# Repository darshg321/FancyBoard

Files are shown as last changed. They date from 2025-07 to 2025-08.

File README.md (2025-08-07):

# FancyBoard

FancyBoard is a custom hot-swappable mechanical keyboard inspired by the k.no.b.1 from Work Louder.

- Hot Swappable
- BlueMicro Firmware
- Low Profile
- Bluetooth & USB-C
- 1.9" IPS Display
- 65% layout
- 2 Dials

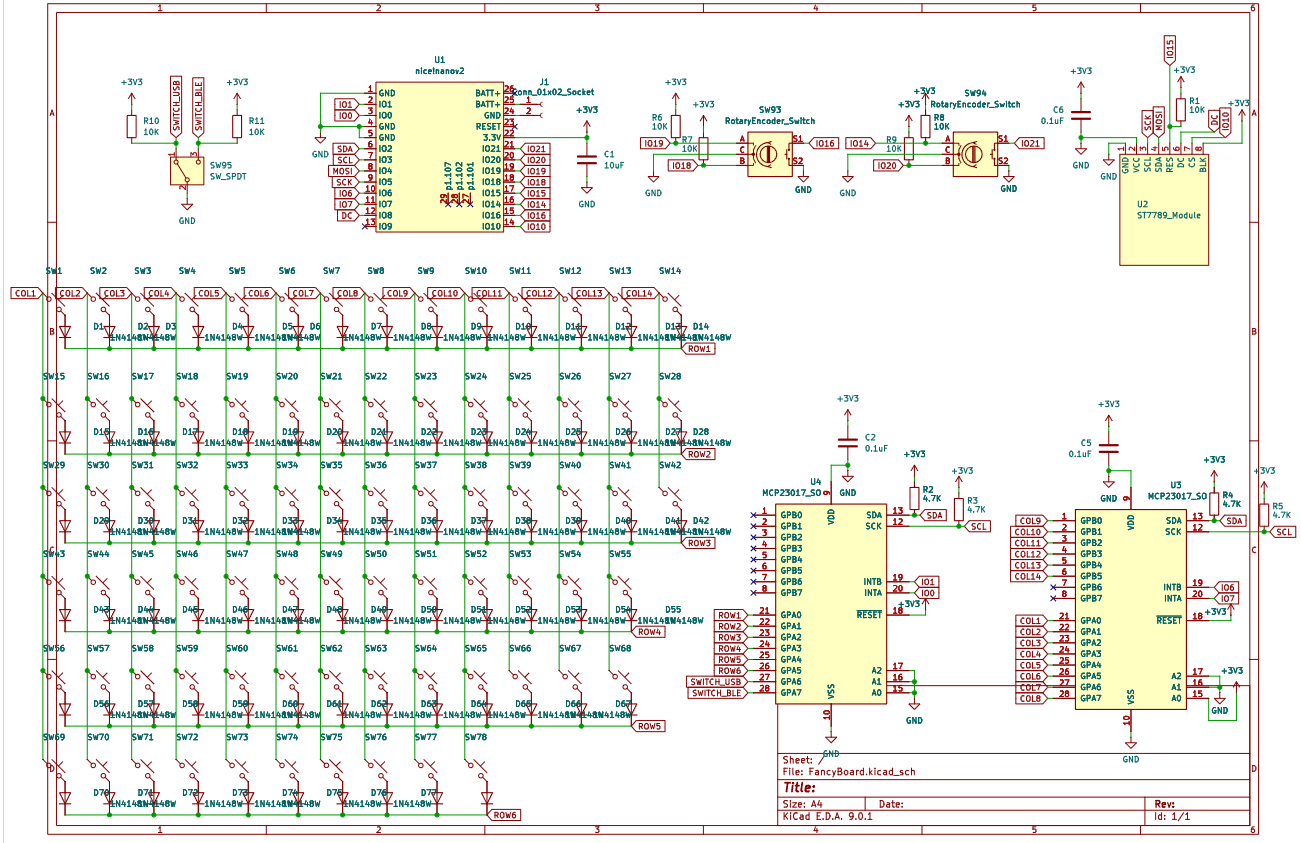
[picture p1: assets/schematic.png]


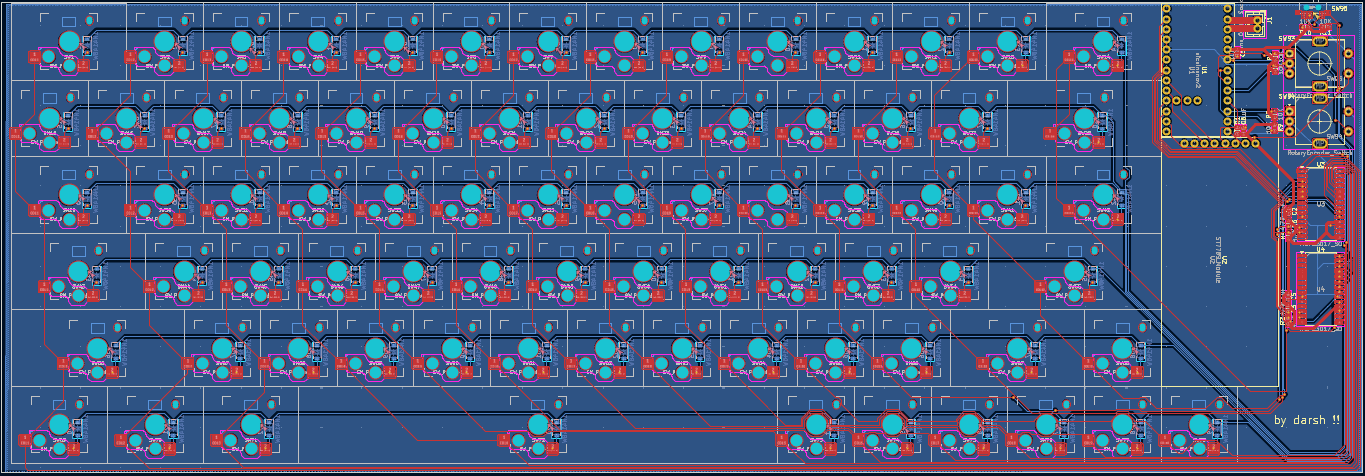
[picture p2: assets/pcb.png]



i made this keyboard because i saw the KNOB keyboard on reels, and thought it was probably the nicest looking keyboard ive seen, but unfortunately its like 400usd, way too expensive

i wanted to learn how to make a full keyboard after hackpad anyways, so i designed this. i also want a bluetooth keyboard because my current keyboard has a cable thats very annoying, and i wanted to replace it.

## BOM
|Reference |Value |Footprint |Qty|Link |Price (USD)|
|---|---|---|---|---|---|
|C1 |10uF |Capacitor_SMD:C_0603_1608Metric |1  |https://www.aliexpress.com/item/1005002761630440.html|3.13 |
|C2,C5,C6 |0.1uF |Capacitor_SMD:C_0603_1608Metric |3  | | |
|D1-D79 |1N4148W |Diode_SMD:D_SOD-123 |78 |https://www.aliexpress.com/item/1005006123061230.html|2.8 |
|J1 |Conn_01x02_Socket |Connector_JST:JST_PH_B2B-PH-K_1x02_P2.00mm_Vertical |1  |https://www.aliexpress.com/item/1005004955655144.html|2 |
|R1,R6,R7,R8,R9,R10,R11|10K |Resistor_SMD:R_0603_1608Metric |7  |https://www.aliexpress.com/item/1005008912576822.html|1.9 |
|R2,R3,R4,R5 |4.7K |Resistor_SMD:R_0603_1608Metric |4  |https://www.aliexpress.com/item/1005008912576822.html|1.9 |
|SW2-SW78 |SW_Push_45deg |Kailh_PG1353_Hotswap:Kailh-PG1353-Hotswap |78 |https://www.aliexpress.com/item/1005008644185126.html|32.61 |
|SW93,SW94 |RotaryEncoder_Switch |Rotary_Encoder:RotaryEncoder_Alps_EC11E-Switch_Vertical_H20mm|2  |https://www.aliexpress.com/item/1005007644083514.html|2.25 |
|SW95 |SW_SPDT |MSK-12C02:MSK-12C02 |1  |https://www.aliexpress.com/item/1005009568929894.html|2.13 |
|U1 |nice!nanov2 |nice!nanov2:nice!nanov2 |1  |https://www.aliexpress.com/item/1005007266112508.html|3.02 |
|U2 |ST7789_Module |ST7789_Module:ST7789_Module |1  |https://www.aliexpress.com/item/1005006042323705.html|2.54 |
|U3,U4 |MCP23017_SO |Package_SO:SOIC-28W_7.5x17.9mm_P1.27mm |2  |https://www.aliexpress.com/item/1005009559642041.html|4.07 |
| |Kailh Choc Stabilizers | |1  |https://www.aliexpress.com/item/1005006528731543.html|8.65 |
| |Kailh Choc Keycaps | |78 |https://www.aliexpress.com/item/1005008146995393.html|15.76 |
| |Kalih Choc Hot Swap Sockets| |78 |https://www.aliexpress.com/item/1005006625852715.html|9.73 |
| |1s LiPo 500mAh Battery | |1  |https://www.aliexpress.com/item/1005007016796736.html|9.15 |
| |PCB | | |https://jlcpcb.com |19 |
| |M2 18mm Screw | | |https://www.aliexpress.com/item/1005007264845313.html|1.89 |
|Subtotal | | | | |122.53 |
|AliExpress Shipping | | | | |14.45 |
|JLCPCB Shipping | | | | |13.14 |
|Total | | | | |150.12 |

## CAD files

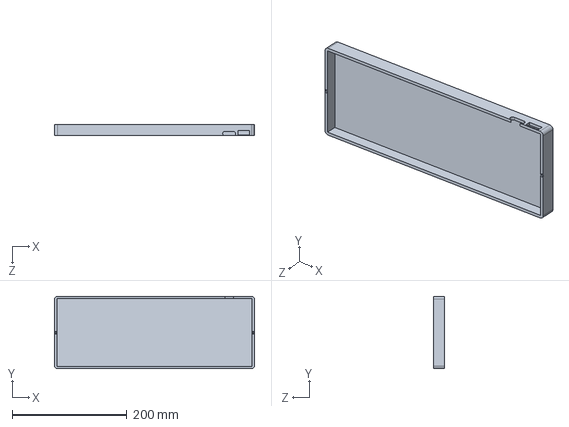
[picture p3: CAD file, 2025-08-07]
cad/bottom.SLDPRT
348.0 x 126.0 x 20.0 mm

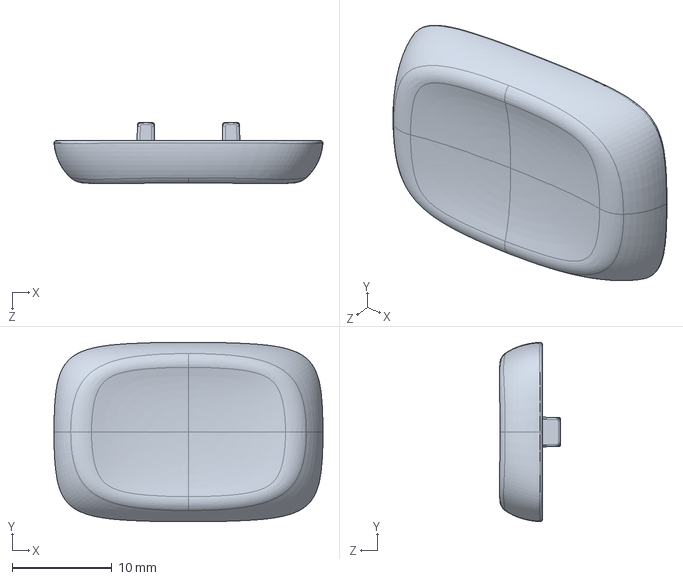
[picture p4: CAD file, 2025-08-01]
cad/keycaps/1.5u.SLDPRT
27.0 x 18.0 x 6.14 mm

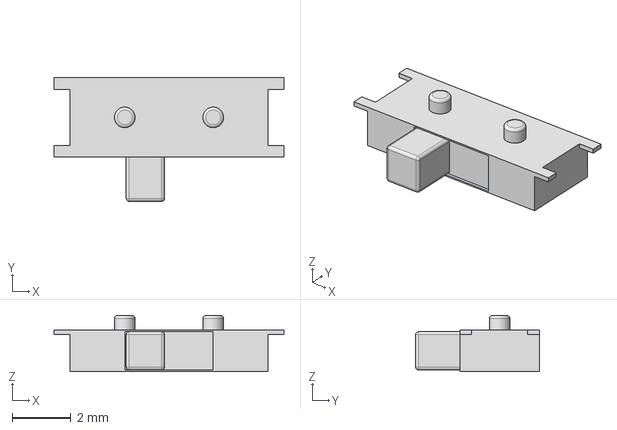
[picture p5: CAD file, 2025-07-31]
pcb/msk12c02.step
7.80 x 4.20 x 1.90 mm

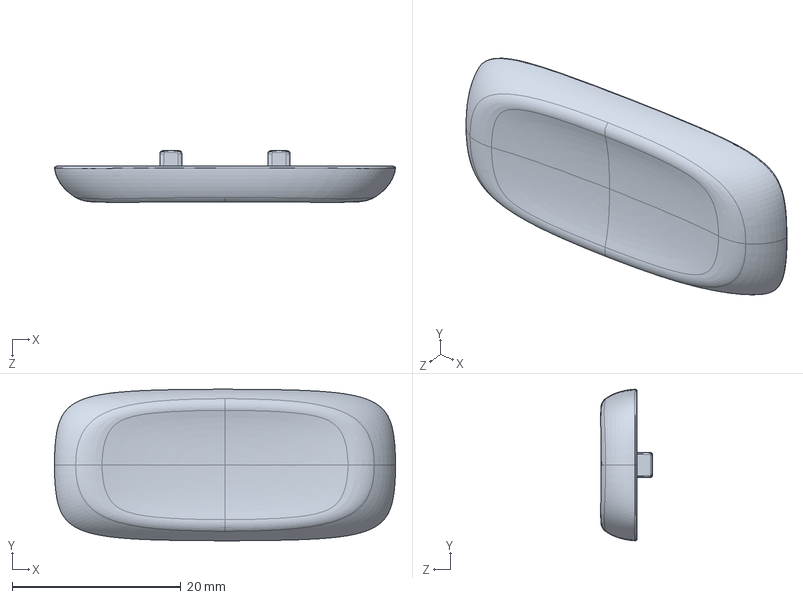
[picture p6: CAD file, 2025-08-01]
cad/keycaps/2.25u.SLDPRT
40.5 x 18.0 x 6.14 mm

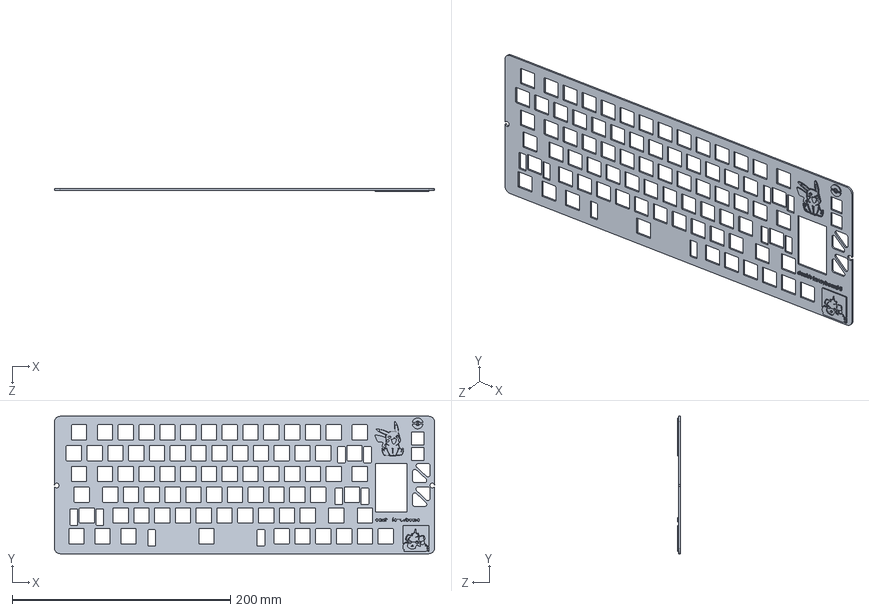
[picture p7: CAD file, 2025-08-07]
cad/top.SLDPRT
348.2 x 126.0 x 2.50 mm

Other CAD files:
cad/PCB Assembly/Kailh-Choc-Socket-CPG135001S30.SLDASM
cad/PCB Assembly/2.0 TFT IPS - Module.SLDASM
cad/PCB Assembly/2.0 TFT IPS - 22P - Reverse Mount - With Glass.SLDASM
cad/PCB Assembly/TSSOP-16 0.65p 4.4mm.SLDASM
cad/PCB Assembly/2.0 TFT IPS - Module_independant1.SLDASM
cad/PCB Assembly/USB C Female SMD v1.SLDASM
cad/PCB Assembly/nice!nano v2.SLDASM
cad/PCB Assembly/mcu-chip-ic-2set-leg v1.SLDASM
cad/PCB Assembly/2.0 TFT IPS - Module_independant.SLDASM
cad/PCB Assembly/FancyBoard 1.SLDASM
cad/PCB Assembly/TSSOP-16 0.65p 4.4mm v1.SLDASM
cad/PCB Assembly/Kailh LP Choc Burnt Orange.SLDPRT
production/bottom.STEP
cad/PCB Assembly/0603 Capacitor.SLDPRT
cad/PCB Assembly/0603 Resistor.SLDPRT
cad/PCB Assembly/2.0 TFT IPS - 22P - Reverse Mount - With Glass-0.SLDPRT
cad/PCB Assembly/2.0 TFT IPS - Glass - Rev.SLDPRT
cad/PCB Assembly/2.0 TFT IPS - Module - Board.SLDPRT
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

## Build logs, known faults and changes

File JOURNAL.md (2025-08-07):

---
title: "FancyBoard"
author: "Darsh Gupta"
description: "A custom, low-profile, hot-swappable mechanical keyboard."
created_at: "2025-07-28"
---

## time spent: 36 hours
## july 28th

speedrunning a keyboard before the 31st, just because

i was inspired for making this keyboard by the KNOB keyboard, which ive seen and always thought looked like the perfect keyboard. unfortunately, its $439, bad, so i'll try to make something similar for $150

KNOB:
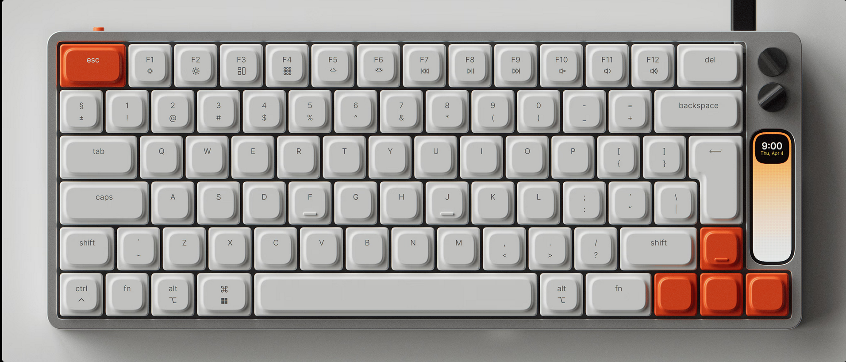
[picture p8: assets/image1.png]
KNOB


planned features:
- nice mechanical switches
- keycaps, i wont be using low profile because i personally dont like it
- hotswappable
- 2 dials
- oled screen
- both usb c and bluetooth connectivity
- usb c charging
- 3000mAh battery for big battery life

ill be using the nice!nano v2 because it consumes very little power, has battery charging built in, and has bluetooth HID + usb c HID already

parts list:

| Component | Part | Notes |
| --- | --- | --- |
| Microcontroller | Nice!Nano V2 | nRF52840 + integrated battery charger |
| Battery | 3.7V Li-ion 3000mAh (flat, JST-PH) | Rechargeable |
| USB Port | JST to USB-C charging cable | Board already has onboard USB |
| Rotary Encoder | EC11 w/ push button | For volume/menu |
| Screen | ST7789 1.14" | SPI, vertical https://www.aliexpress.com/item/1005009445748262.html |

| Component | Part | Notes |
| --- | --- | --- |
| Switches | 78x Tactile MX Switches | |
| Diodes | 1N4148W SMD | |
| Hotswap Sockets | 78x Kailh MX sockets | |
| Keycaps | SA / DSA / OEM profile | PC or PBT preferred |
| Encoder Knob | Aluminum / ABS cap | |

# schematic

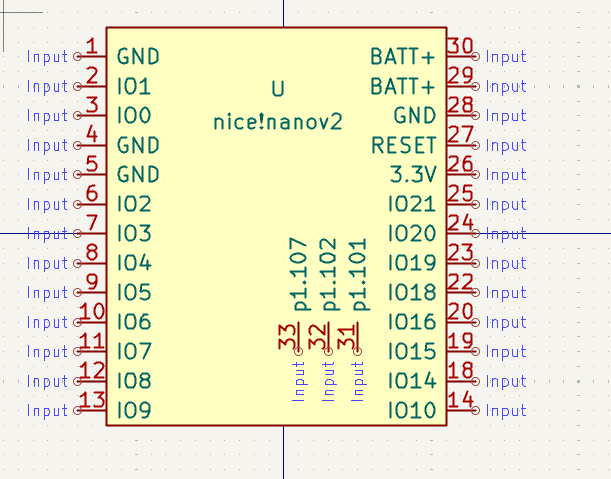
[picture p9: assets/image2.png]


microcontroller symbol done!

+3 hours

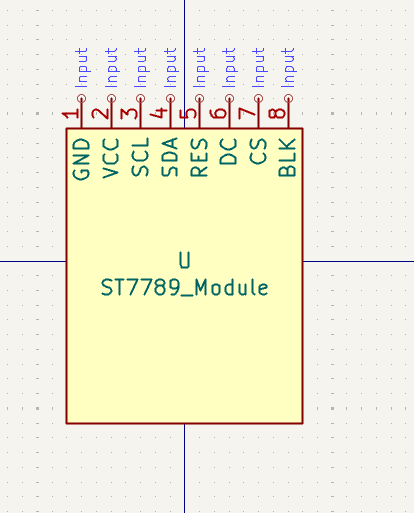
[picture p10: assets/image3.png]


done with ST7789_Module symbol

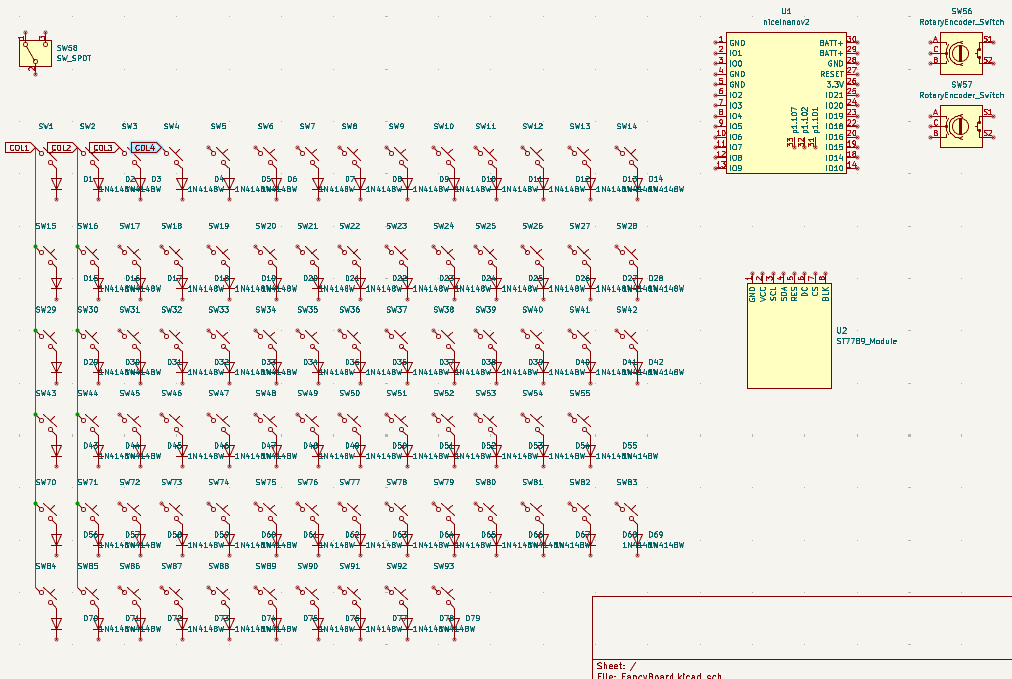
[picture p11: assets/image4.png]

current progress of schematic

+2 hours

adding 2 MCP23017 because i need a lot more io

## july 29th

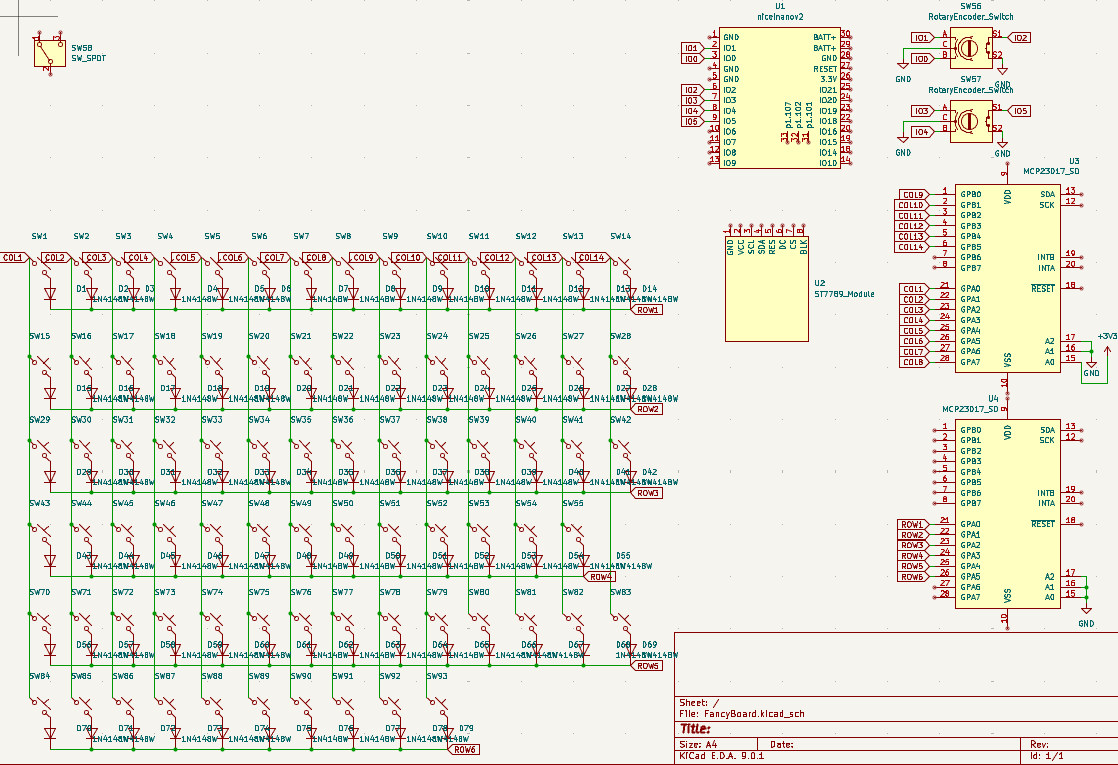
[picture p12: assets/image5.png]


added all the components, need to complete wiring

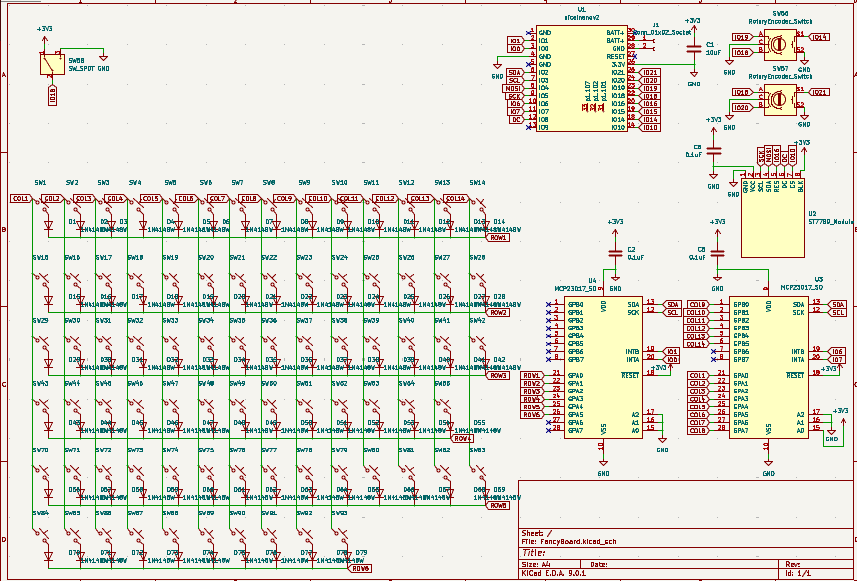
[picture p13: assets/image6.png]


finished most of everything, need to add some pull up resistors and capacitors and stuff

+3 hours

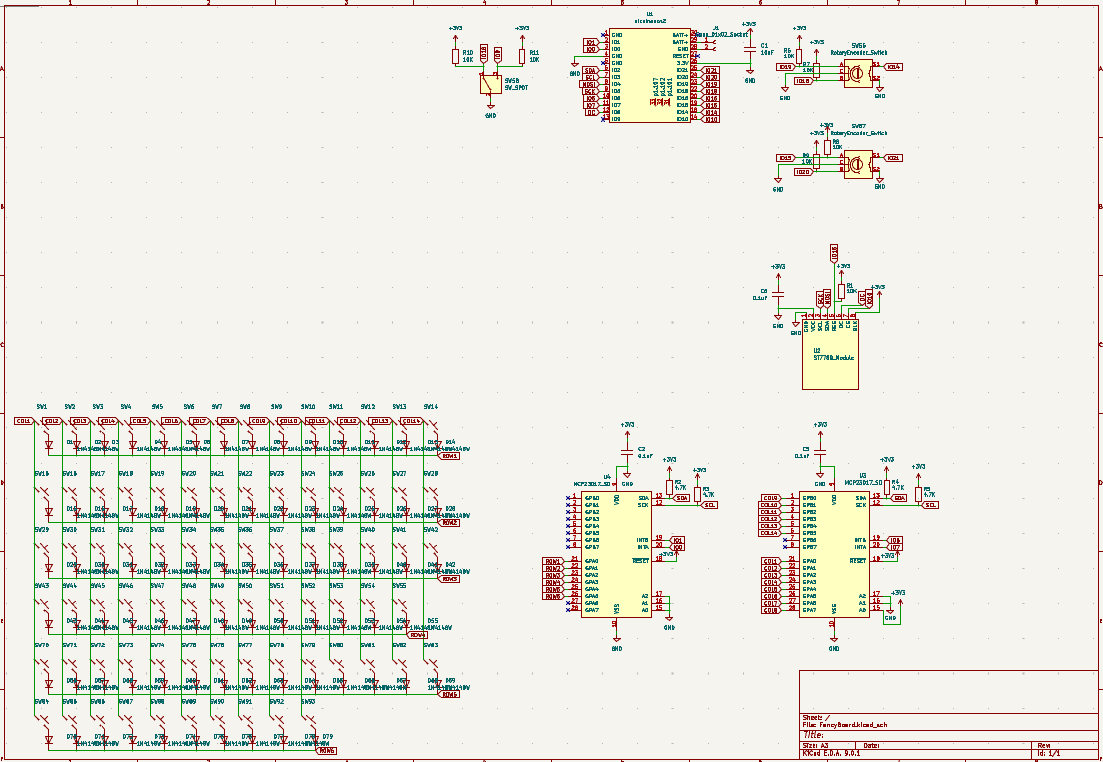
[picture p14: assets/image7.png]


done with schematic, pull ups and capacitors

need to make footprints and assignments

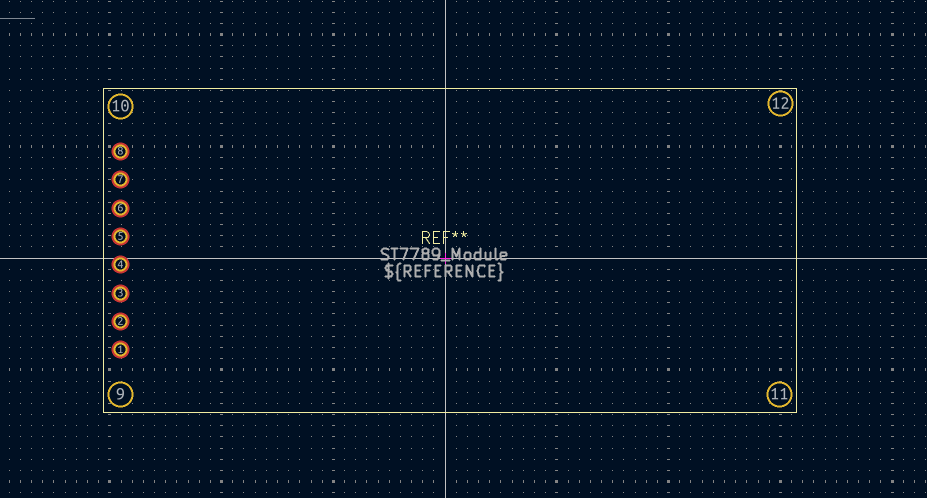
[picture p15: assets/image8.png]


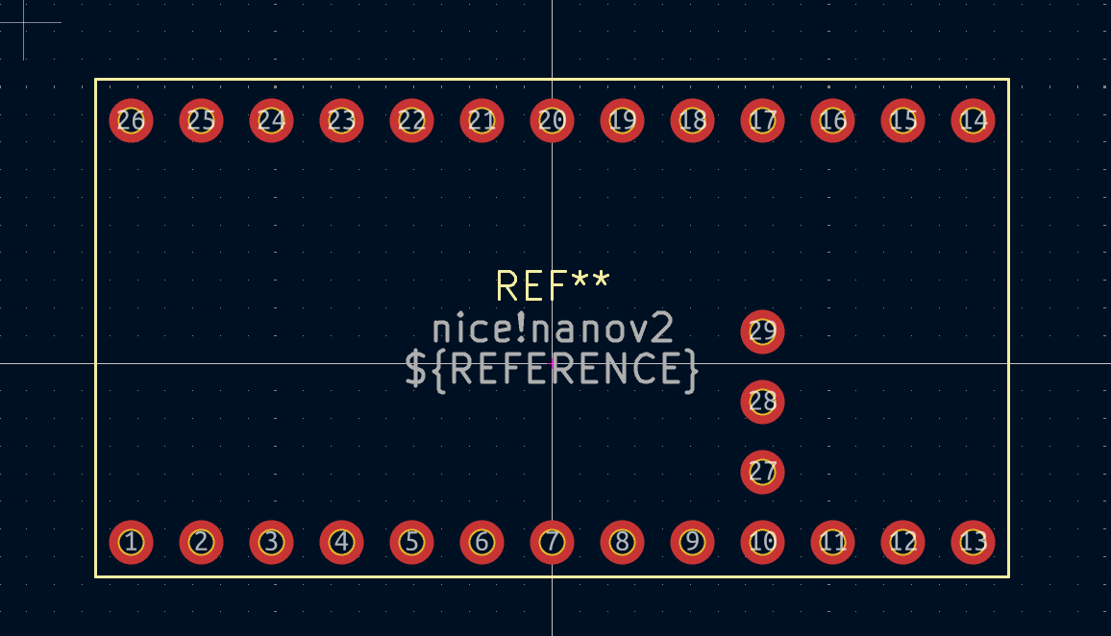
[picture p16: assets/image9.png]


done with both footprints

+3 hours

keycaps: https://www.aliexpress.com/item/1005004840360158.html

deciding on Kailih Choc V2 Low Profile Switches

stabalizers: https://www.aliexpress.com/item/1005001781468636.html

spdt switch: SS12D00

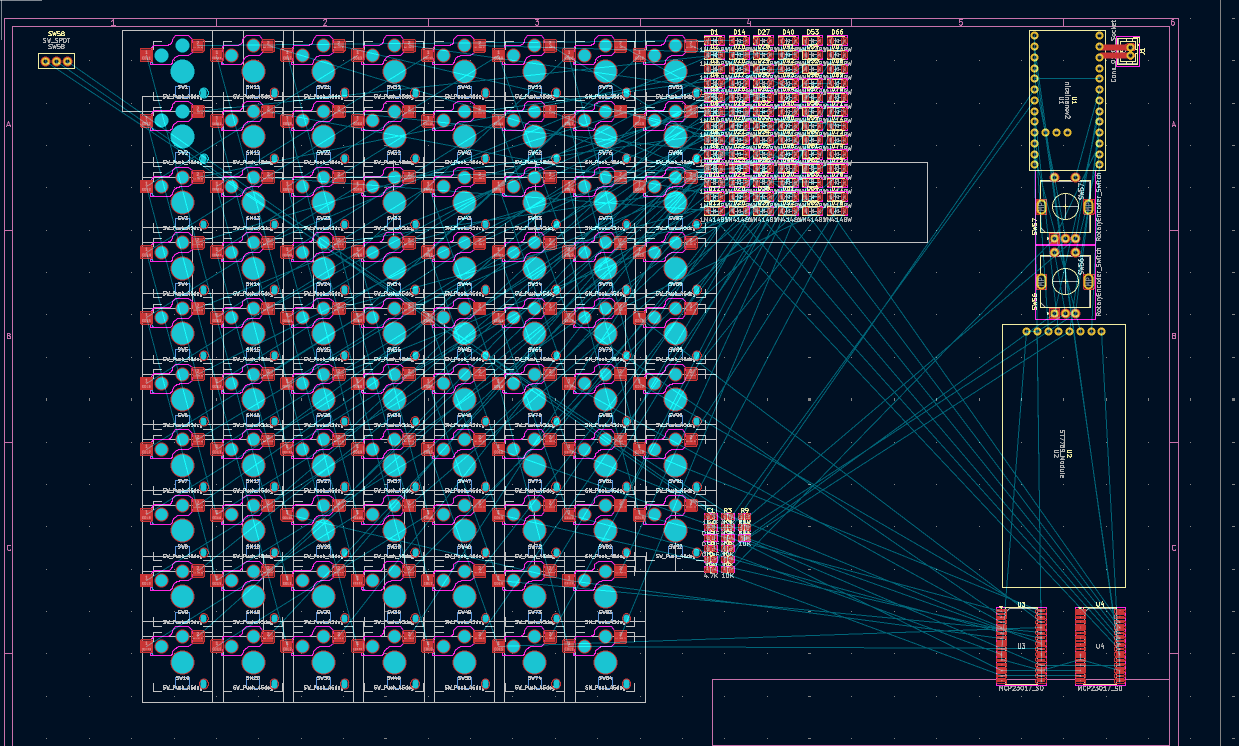
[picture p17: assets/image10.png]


fixed a few symbol and footprint issues, starting pcb

switching to choc v1 because its easier
https://shop.beekeeb.com/product/kailh-choc-v1-hotswap-socket/

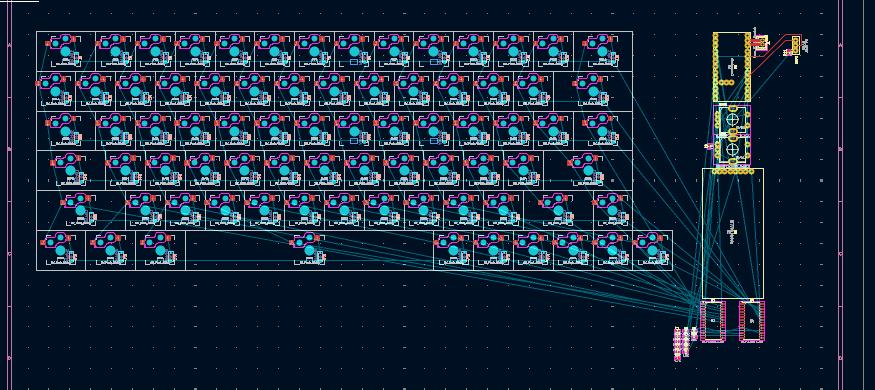
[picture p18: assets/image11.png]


fixed the layout, need to route now

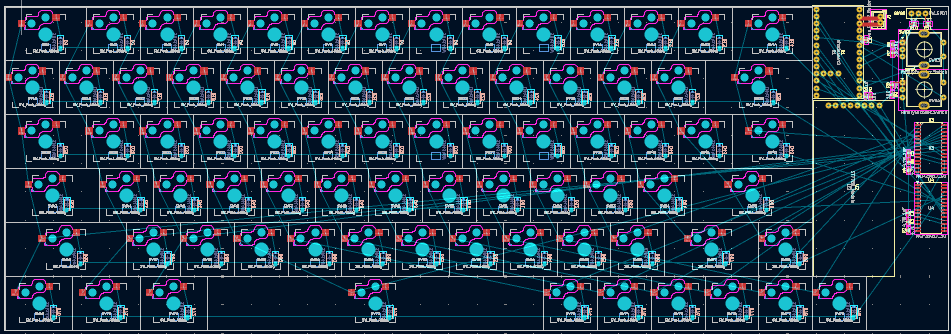
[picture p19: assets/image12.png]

finshed layout fully, routing time

+5 hours

## july 30th

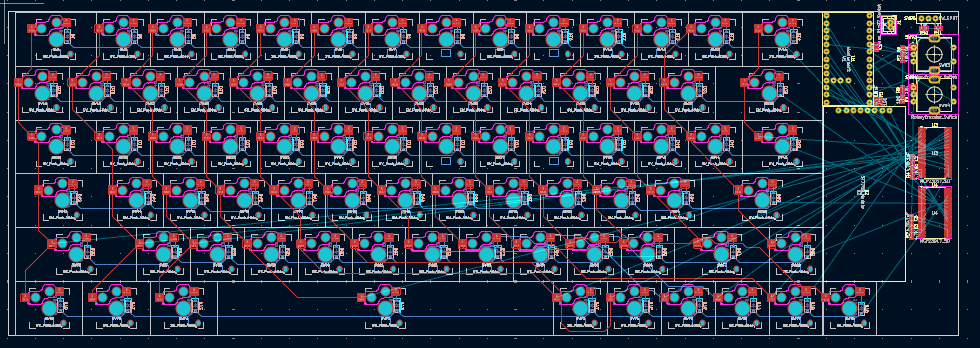
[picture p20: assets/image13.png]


almost finished routing, need to route rows/columns and other components

finished routing rows and columns
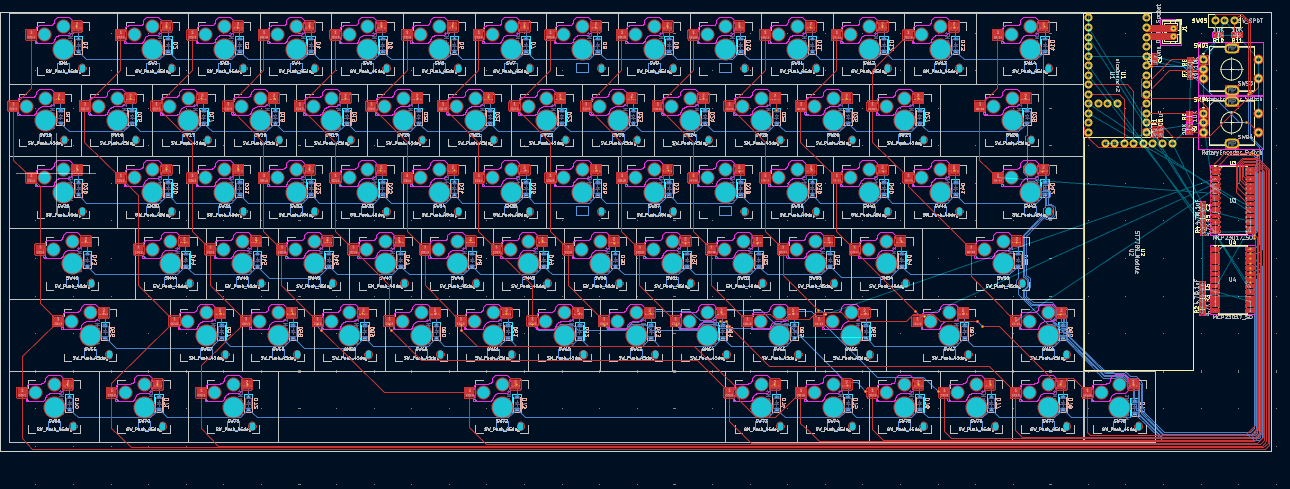
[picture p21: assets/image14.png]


apparently the footprint library had the sockets flipped, so i had to edit the footprint library and then reroute all the keys unfortunately

cooked but oh well

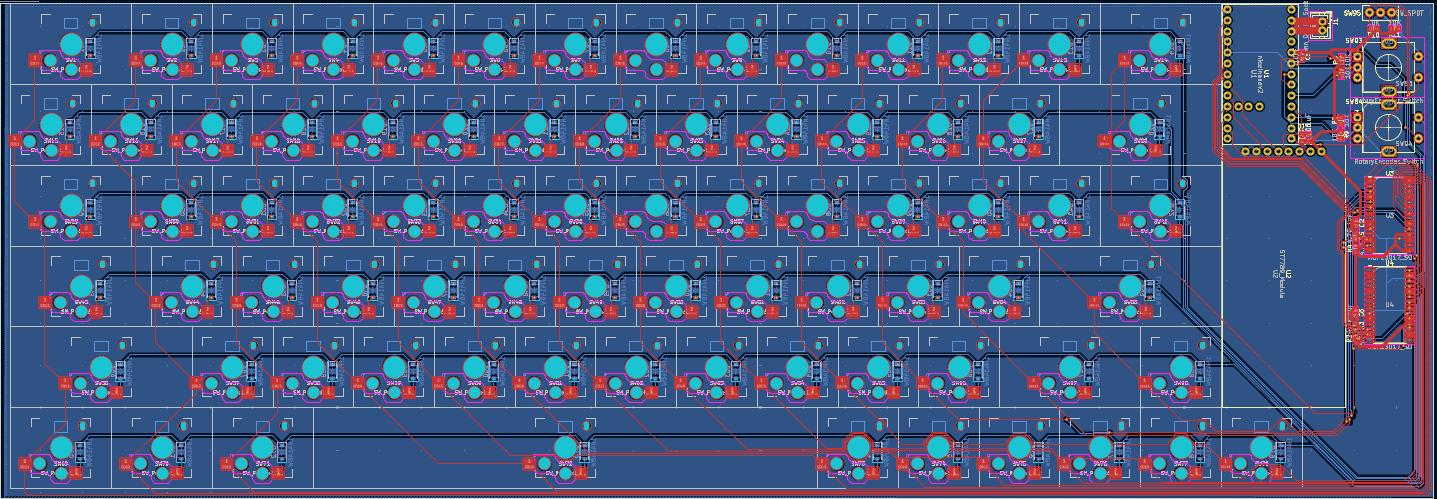
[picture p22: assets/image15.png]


+4 hours

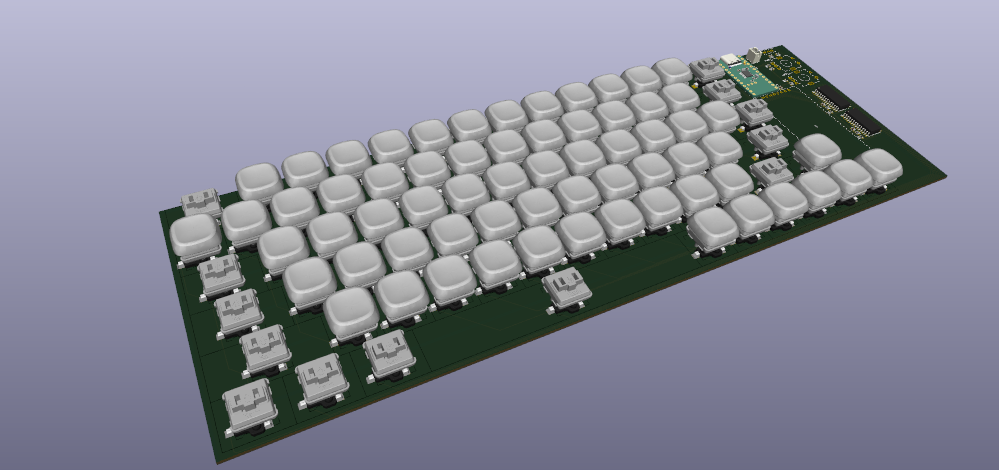
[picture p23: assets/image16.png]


completely finished pcb, working on models

+2 hours

changed switch, cleaned up some wiring, added 3d models for everything, changed some footprints

pcb fully done !!





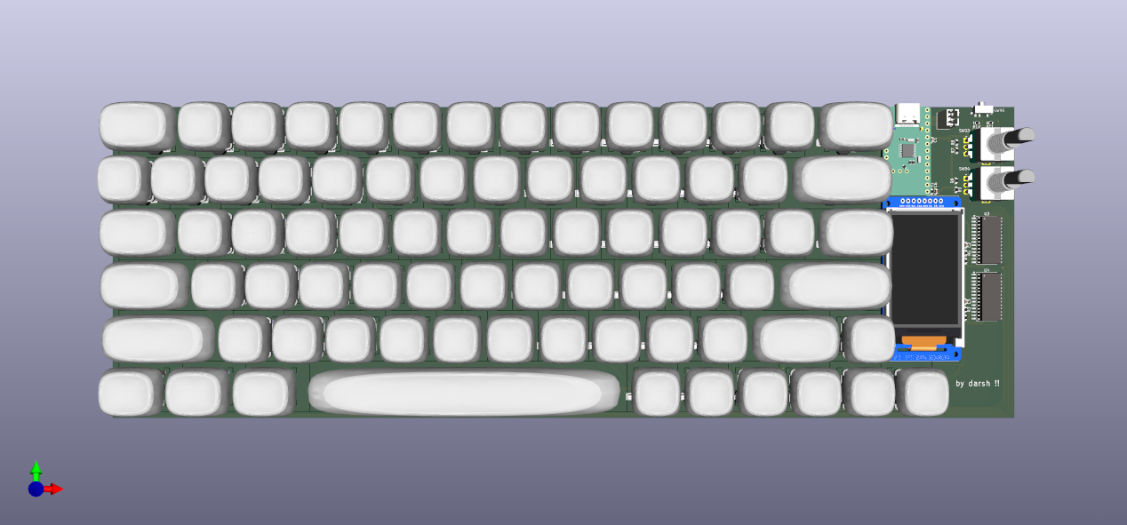
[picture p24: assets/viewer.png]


+2 hours

## july 31st

manually adding keys cause kicad doesnt export stretched components properly (its sooooo slow)

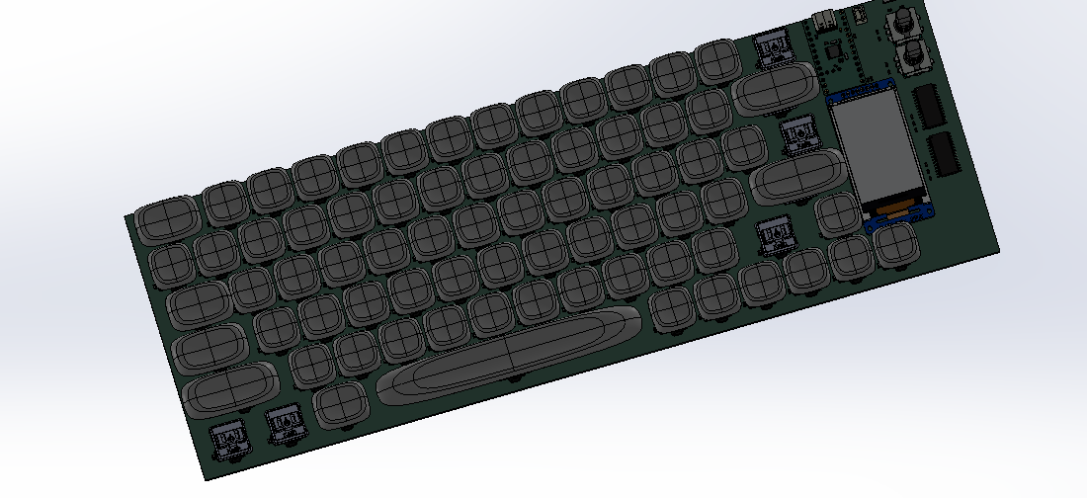
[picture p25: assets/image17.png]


also made the bom

+3 hours

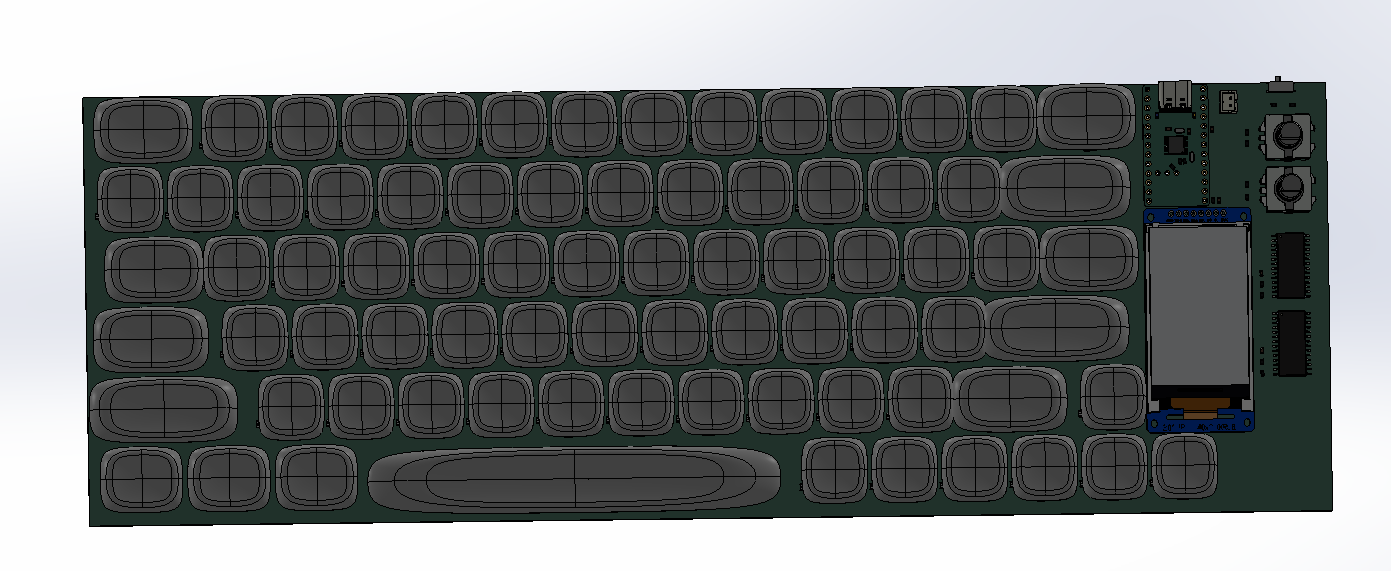
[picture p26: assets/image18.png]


done with pcb cad

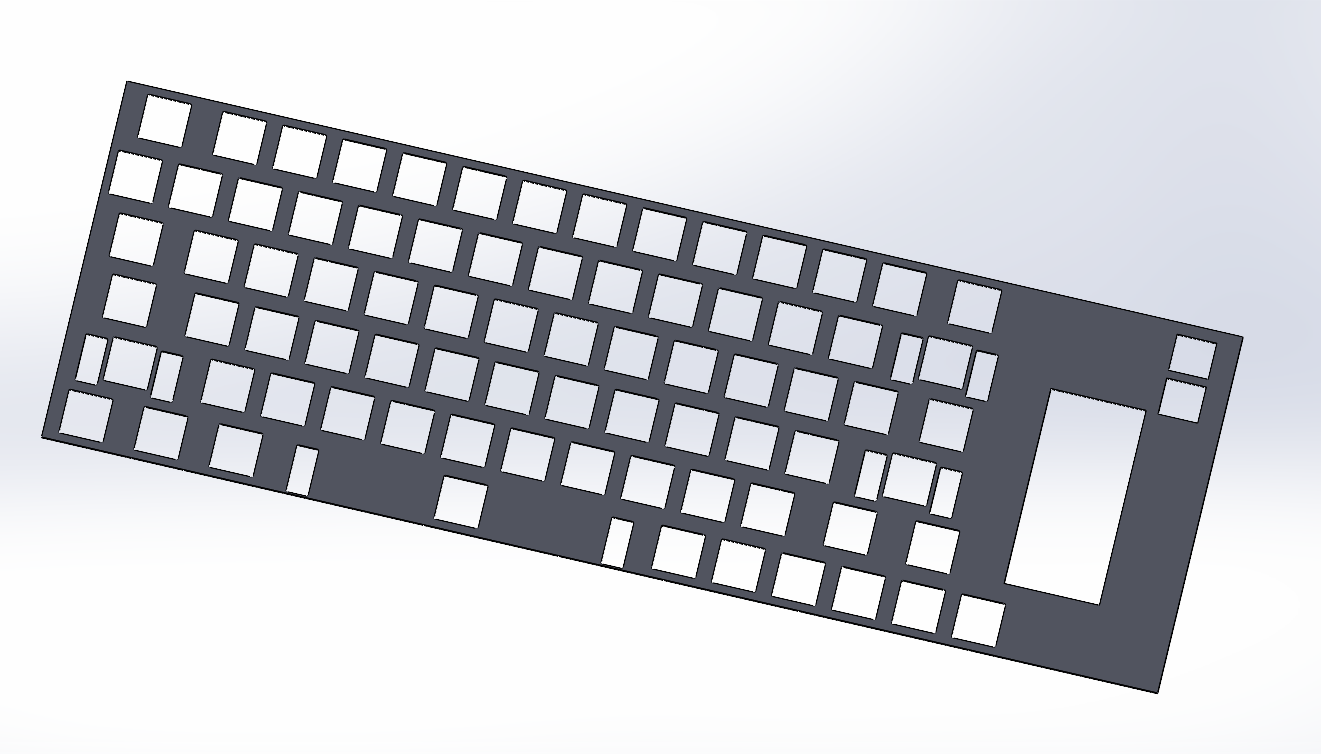
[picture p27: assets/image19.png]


top plate cad done

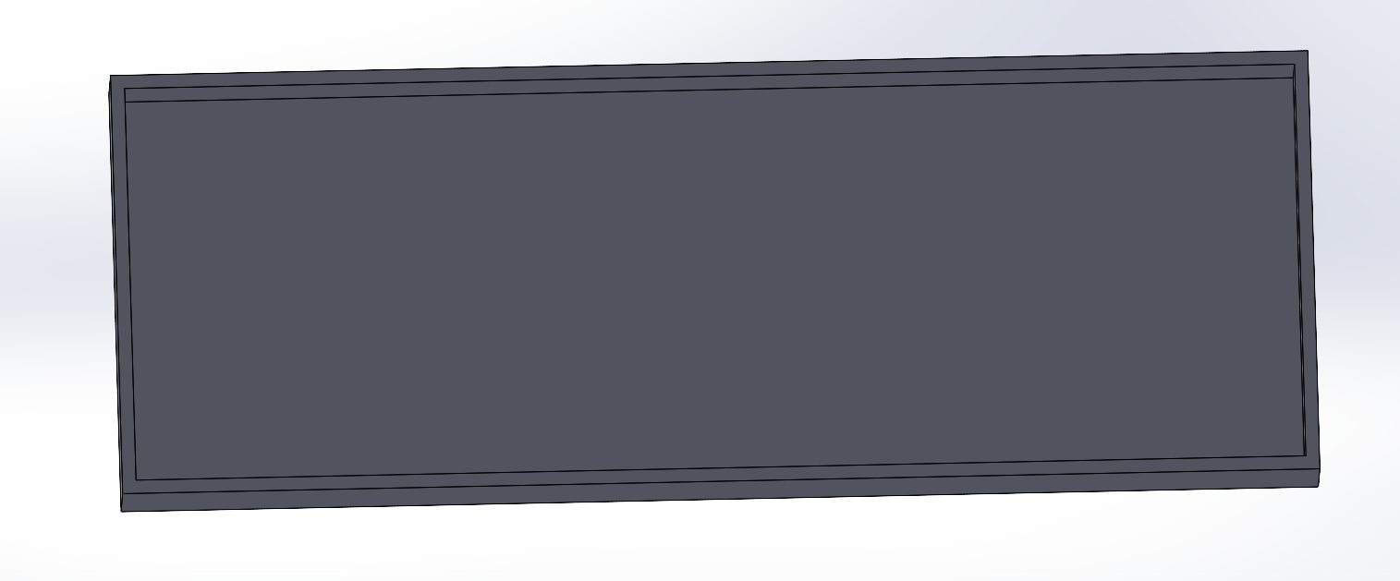
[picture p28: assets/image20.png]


bottom plate mostly done, need to add usb cutout still

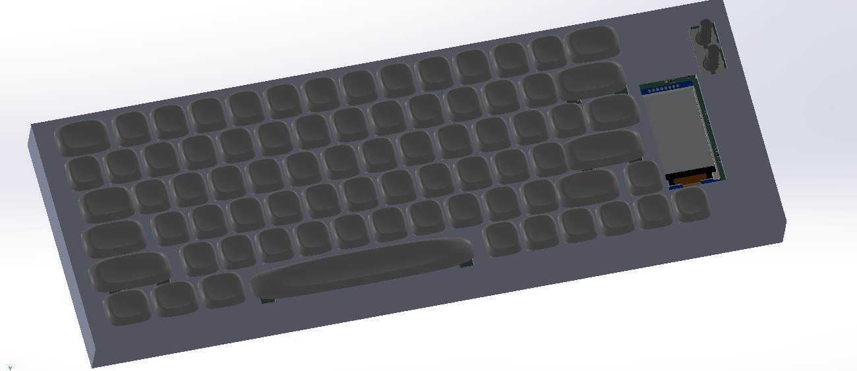
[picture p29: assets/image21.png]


working on case

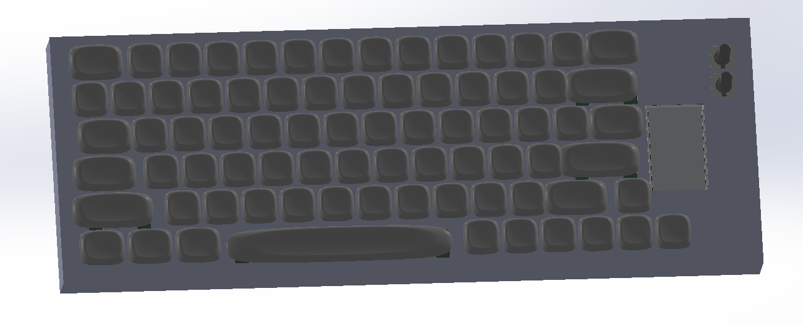
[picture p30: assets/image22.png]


cad mostly done need to add some design later

+4 hours

firmware:

based it on the bt75_v1 firmware, as its very similar

using https://nickcoutsos.github.io/keymap-editor/, i edited a zmk keymap for the keyboard

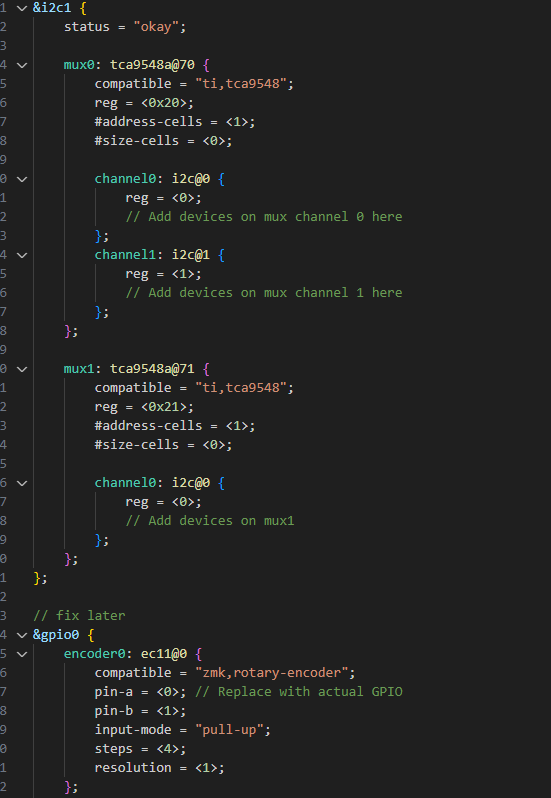
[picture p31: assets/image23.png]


after some chatgpt consulting and perusing the docs, zmk is actually really complicated and lowkey a little gibberish, so im gonna switch over to bluemicron firmware, which also supports the nicenanov2 and has bluetooth, but uses arduino c instead of the mess zmk has

learning bluemicro: copied over repo and made my project, starting on config

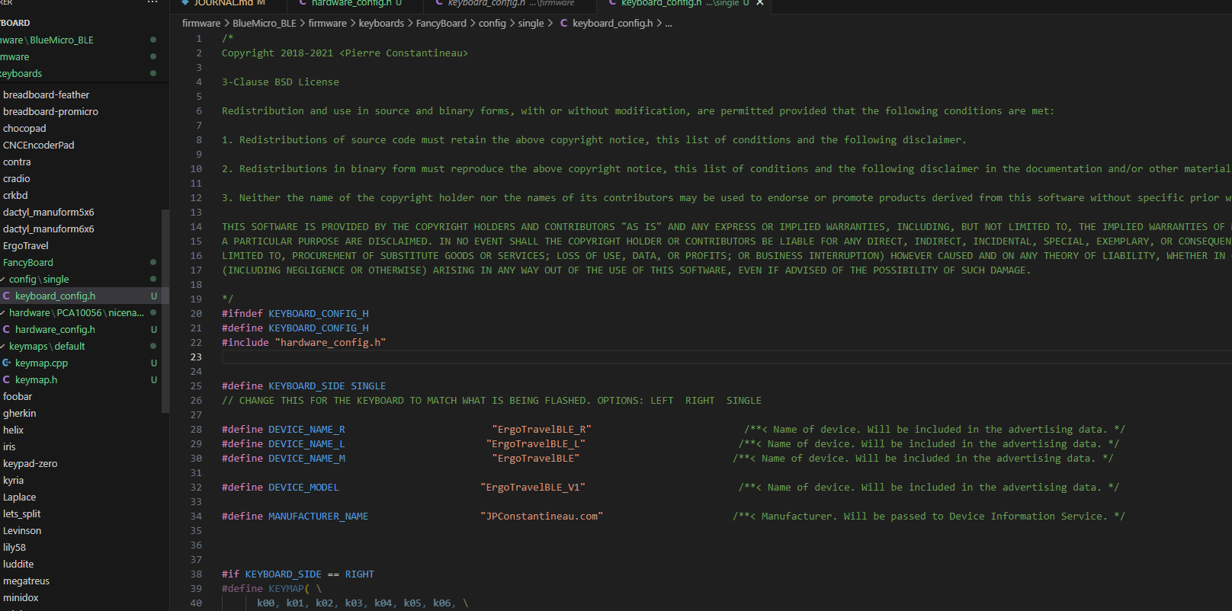
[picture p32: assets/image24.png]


finished code, mostly default but it should work

changed a bunch of BOM stuff to make pricing work

+2 hours

added cad designs
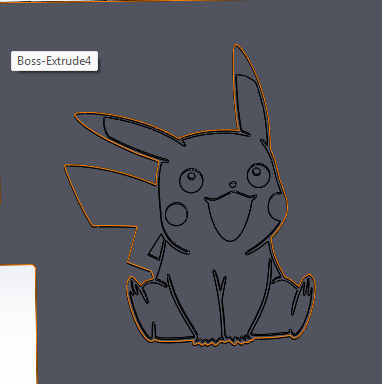
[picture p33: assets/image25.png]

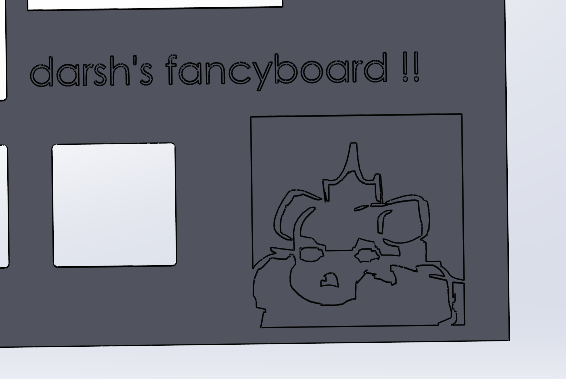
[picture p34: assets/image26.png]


done !!

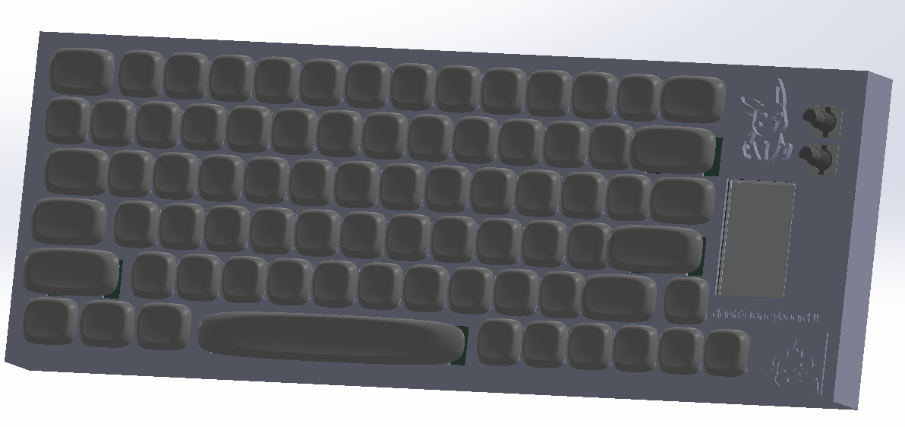
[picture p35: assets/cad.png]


added render, filleted corners, assigned appearance to everything

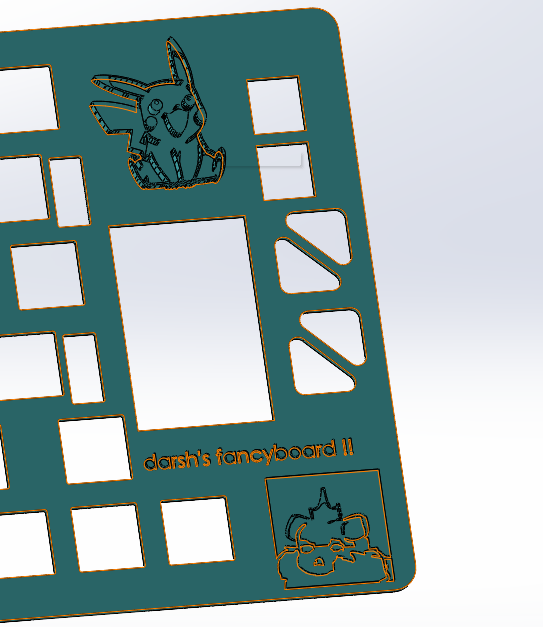
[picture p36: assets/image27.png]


added holes w fillet

+2 hours

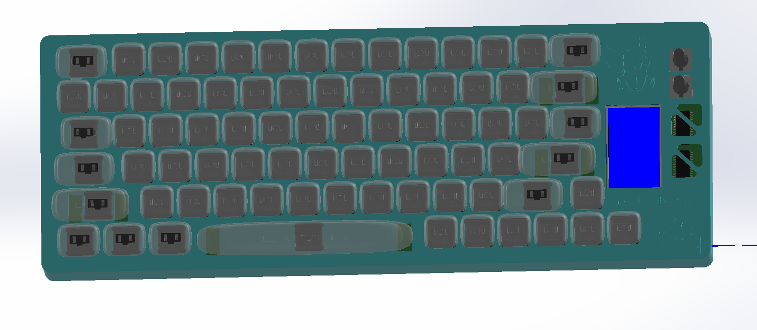
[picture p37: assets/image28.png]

changing design




finished editing plate

+1 hour


added mounting holes, m2 screws (hole is 18mm down)

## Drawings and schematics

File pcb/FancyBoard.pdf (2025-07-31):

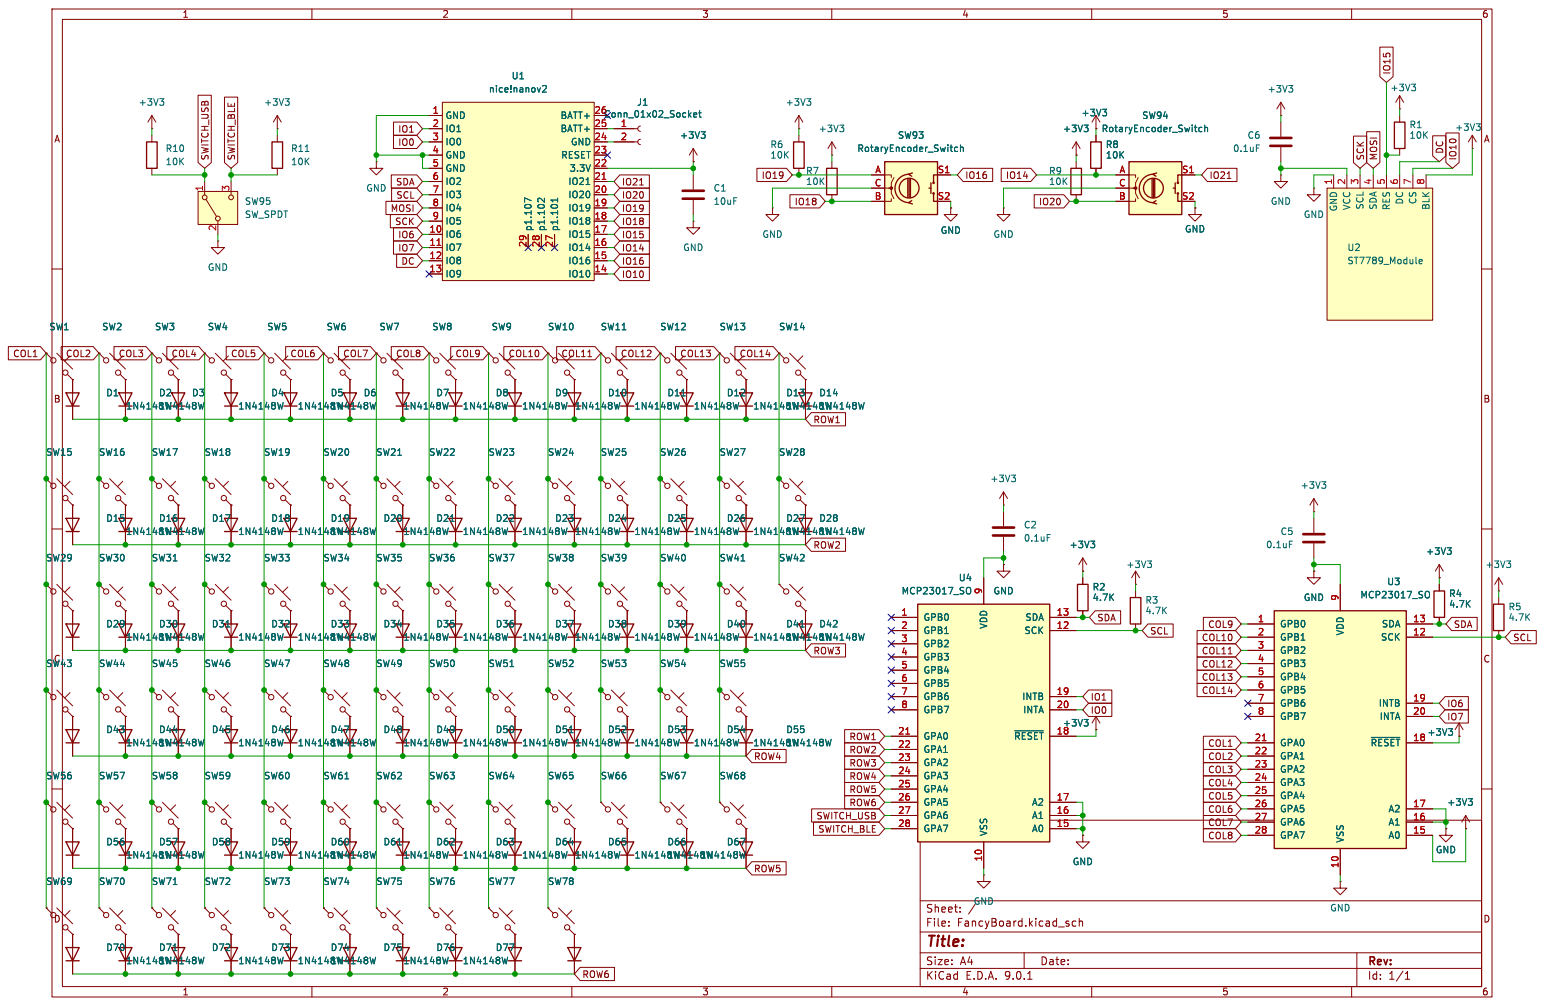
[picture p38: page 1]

Id: 1/1 Title: File: FancyBoard.kicad_sch Sheet: / D70

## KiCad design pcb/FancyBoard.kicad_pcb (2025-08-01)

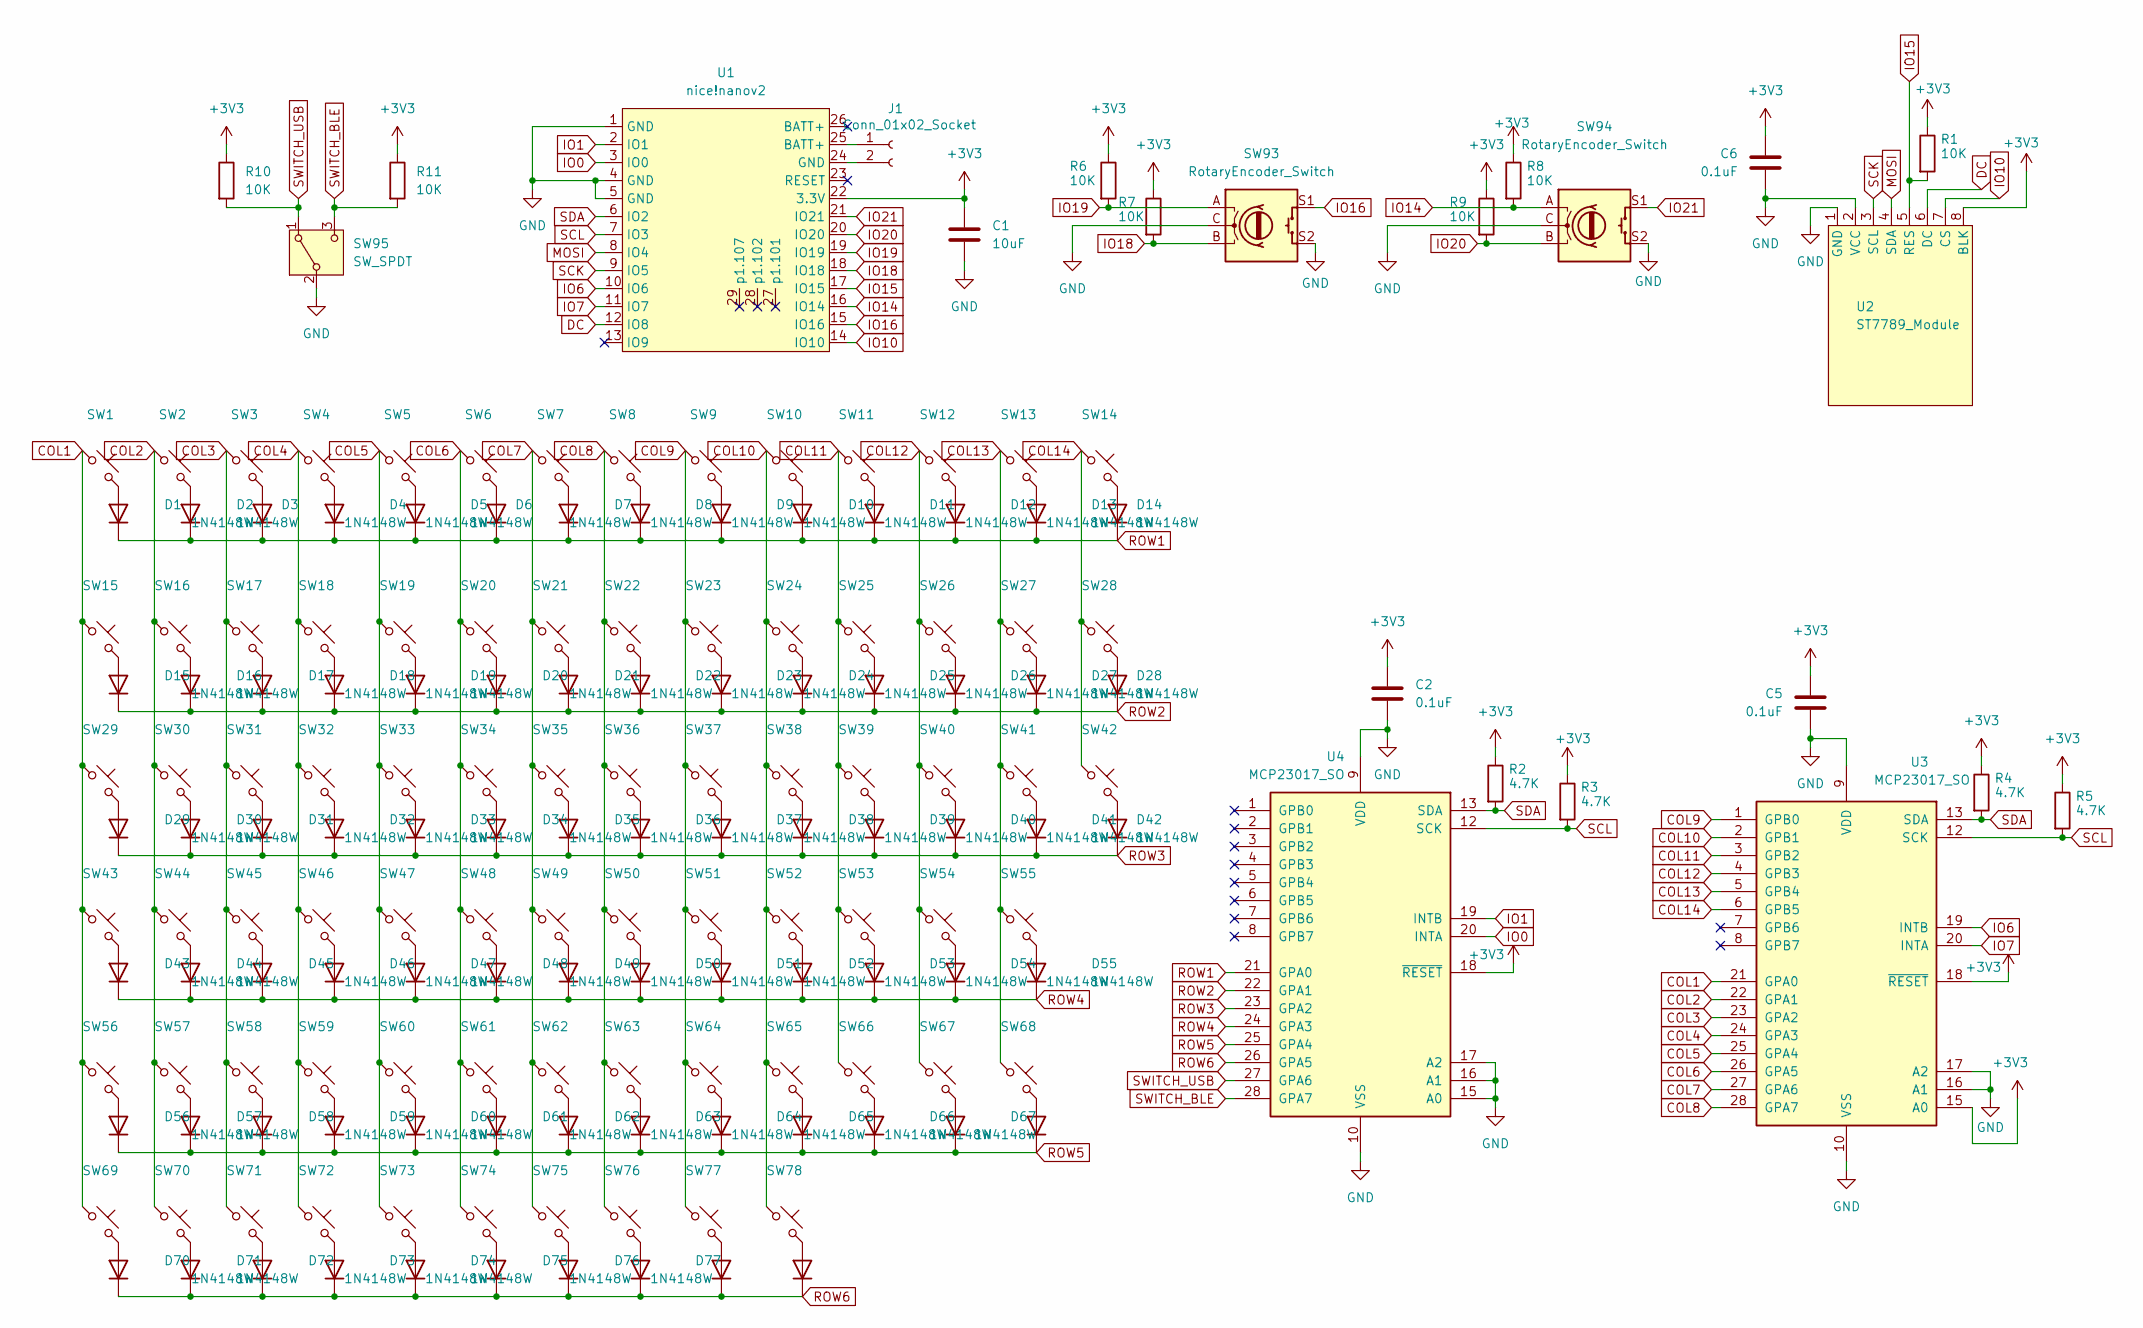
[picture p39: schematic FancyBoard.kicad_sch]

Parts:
C1: 10uF; C_0603_1608Metric
C2, C5, C6: 0.1uF; C_0603_1608Metric
D1, D2, D3, D4, D5, D6, D7, D8, D9, D10, D11, D12, D13, D14, D15, D16, D17, D18, D19, D20, D21, D22, D23, D24, D25, D26, D27, D28, D29, D30, D31, D32, D33, D34, D35, D36, D37, D38, D39, D40, D41, D42, D43, D44, D45, D46, D47, D48, D49, D50, D51, D52, D53, D54, D55, D56, D57, D58, D59, D60, D61, D62, D63, D64, D65, D66, D67, D68, D70, D71, D72, D73, D74, D75, D76, D77, D78, D79: 1N4148W; D_SOD-123
J1: Conn_01x02_Socket; JST_PH_B2B-PH-K_1x02_P2.00mm_Vertical
R1, R6, R7, R8, R9, R10, R11: 10K; R_0603_1608Metric
R2, R3, R4, R5: 4.7K; R_0603_1608Metric
SW1, SW14, SW29, SW42: SW_Push_45deg; Kailh-PG1353-Hotswap-1.5U
SW2, SW3, SW4, SW5, SW6, SW7, SW8, SW9, SW10, SW11, SW12, SW13, SW15, SW16, SW17, SW18, SW19, SW20, SW21, SW22, SW23, SW24, SW25, SW26, SW27, SW30, SW31, SW32, SW33, SW34, SW35, SW36, SW37, SW38, SW39, SW40, SW41, SW44, SW45, SW46, SW47, SW48, SW49, SW50, SW51, SW52, SW53, SW54, SW57, SW58, SW59, SW60, SW61, SW62, SW63, SW64, SW65, SW66, SW68, SW73, SW74, SW75, SW76, SW77, SW78: SW_Push_45deg; Kailh-PG1353-Hotswap-1U
SW28: SW_Push_45deg; Kailh-PG1353-Hotswap-2U
SW43, SW67: SW_Push_45deg; Kailh-PG1353-Hotswap-1.75U
SW55, SW56: SW_Push_45deg; Kailh-PG1353-Hotswap-2.25U
SW69, SW70, SW71: SW_Push_45deg; Kailh-PG1353-Hotswap-1.25U
SW72: SW_Push_45deg; Kailh-PG1353-Hotswap-6.25U
SW93, SW94: RotaryEncoder_Switch; RotaryEncoder_Alps_EC11E-Switch_Vertical_H20mm
SW95: SW_SPDT; MSK-12C02
U1: nice!nanov2
U2: ST7789_Module
U3, U4: MCP23017_SO; SOIC-28W_7.5x17.9mm_P1.27mm

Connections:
+3V3: C1.1, C2.1, C5.1, C6.1, R1.1, R2.1, R3.1, R4.1, R5.1, R6.1, R7.1, R8.1, R9.1, R10.1, R11.1, U1.22 (3.3V), U2.8 (BLK), U3.15 (A0), U3.18 (~RESET), U4.18 (~RESET)
COL1: SW1.1, SW15.1, SW29.1, SW43.1, SW56.1, SW69.1, U3.21 (GPA0)
COL2: SW2.1, SW16.1, SW30.1, SW44.1, SW57.1, SW70.1, U3.22 (GPA1)
COL3: SW3.1, SW17.1, SW31.1, SW45.1, SW58.1, SW71.1, U3.23 (GPA2)
COL4: SW4.1, SW18.1, SW32.1, SW46.1, SW59.1, SW72.1, U3.24 (GPA3)
COL5: SW5.1, SW19.1, SW33.1, SW47.1, SW60.1, SW73.1, U3.25 (GPA4)
COL6: SW6.1, SW20.1, SW34.1, SW48.1, SW61.1, SW74.1, U3.26 (GPA5)
COL7: SW7.1, SW21.1, SW35.1, SW49.1, SW62.1, SW75.1, U3.27 (GPA6)
COL8: SW8.1, SW22.1, SW36.1, SW50.1, SW63.1, SW76.1, U3.28 (GPA7)
COL9: SW9.1, SW23.1, SW37.1, SW51.1, SW64.1, SW77.1, U3.1 (GPB0)
COL10: SW10.1, SW24.1, SW38.1, SW52.1, SW65.1, SW78.1, U3.2 (GPB1)
COL11: SW11.1, SW25.1, SW39.1, SW53.1, SW66.1, U3.3 (GPB2)
COL12: SW12.1, SW26.1, SW40.1, SW54.1, SW67.1, U3.4 (GPB3)
COL13: SW13.1, SW27.1, SW41.1, SW55.1, SW68.1, U3.5 (GPB4)
COL14: SW14.1, SW28.1, SW42.1, U3.6 (GPB5)
DC: U1.12 (IO8), U2.6 (DC)
GND: C1.2, C2.2, C5.2, C6.2, SW93.C, SW93.S2, SW94.C, SW94.S2, SW95.2 (B), U1.1 (GND), U1.4 (GND), U1.5 (GND), U2.1 (GND), U2.2 (VCC), U3.9 (VDD), U3.10 (VSS), U3.16 (A1), U3.17 (A2), U4.9 (VDD), U4.10 (VSS), U4.15 (A0), U4.16 (A1), U4.17 (A2)
IO0: U1.3 (IO0), U4.20 (INTA)
IO1: U1.2 (IO1), U4.19 (INTB)
IO6: U1.10 (IO6), U3.19 (INTB)
IO7: U1.11 (IO7), U3.20 (INTA)
IO10: U1.14 (IO10), U2.7 (CS)
IO14: R8.2, SW94.A, U1.16 (IO14)
IO15: R1.2, U1.17 (IO15), U2.5 (RES)
IO16: SW93.S1, U1.15 (IO16)
IO18: R7.2, SW93.B, U1.18 (IO18)
IO19: R6.2, SW93.A, U1.19 (IO19)
IO20: R9.2, SW94.B, U1.20 (IO20)
IO21: SW94.S1, U1.21 (IO21)
MOSI: U1.8 (IO4), U2.4 (SDA)
unnamed: D1.2 (A), SW1.2
unnamed: D2.2 (A), SW2.2
unnamed: D3.2 (A), SW3.2
unnamed: D4.2 (A), SW4.2
unnamed: D5.2 (A), SW5.2
unnamed: D6.2 (A), SW6.2
unnamed: D7.2 (A), SW7.2
unnamed: D8.2 (A), SW8.2
unnamed: D9.2 (A), SW9.2
unnamed: D10.2 (A), SW10.2
unnamed: D11.2 (A), SW11.2
unnamed: D12.2 (A), SW12.2
unnamed: D13.2 (A), SW13.2
unnamed: D14.2 (A), SW14.2
unnamed: D15.2 (A), SW15.2
unnamed: D16.2 (A), SW16.2
unnamed: D17.2 (A), SW17.2
unnamed: D18.2 (A), SW18.2
unnamed: D19.2 (A), SW19.2
unnamed: D20.2 (A), SW20.2
unnamed: D21.2 (A), SW21.2
unnamed: D22.2 (A), SW22.2
unnamed: D23.2 (A), SW23.2
unnamed: D24.2 (A), SW24.2
unnamed: D25.2 (A), SW25.2
unnamed: D26.2 (A), SW26.2
unnamed: D27.2 (A), SW27.2
unnamed: D28.2 (A), SW28.2
unnamed: D29.2 (A), SW29.2
unnamed: D30.2 (A), SW30.2
unnamed: D31.2 (A), SW31.2
unnamed: D32.2 (A), SW32.2
unnamed: D33.2 (A), SW33.2
unnamed: D34.2 (A), SW34.2
unnamed: D35.2 (A), SW35.2
unnamed: D36.2 (A), SW36.2
unnamed: D37.2 (A), SW37.2
unnamed: D38.2 (A), SW38.2
unnamed: D39.2 (A), SW39.2
unnamed: D40.2 (A), SW40.2
unnamed: D41.2 (A), SW41.2
unnamed: D42.2 (A), SW42.2
unnamed: D43.2 (A), SW43.2
unnamed: D44.2 (A), SW44.2
unnamed: D45.2 (A), SW45.2
unnamed: D46.2 (A), SW46.2
unnamed: D47.2 (A), SW47.2
unnamed: D48.2 (A), SW48.2
unnamed: D49.2 (A), SW49.2
unnamed: D50.2 (A), SW50.2
unnamed: D51.2 (A), SW51.2
unnamed: D52.2 (A), SW52.2
unnamed: D53.2 (A), SW53.2
unnamed: D54.2 (A), SW54.2
unnamed: D55.2 (A), SW55.2
unnamed: D56.2 (A), SW56.2
unnamed: D57.2 (A), SW57.2
unnamed: D58.2 (A), SW58.2
unnamed: D59.2 (A), SW59.2
unnamed: D60.2 (A), SW60.2
unnamed: D61.2 (A), SW61.2
unnamed: D62.2 (A), SW62.2
unnamed: D63.2 (A), SW63.2
unnamed: D64.2 (A), SW64.2
unnamed: D65.2 (A), SW65.2
unnamed: D66.2 (A), SW66.2
unnamed: D67.2 (A), SW67.2
unnamed: D68.2 (A), SW68.2
unnamed: D70.2 (A), SW69.2
unnamed: D71.2 (A), SW70.2
unnamed: D72.2 (A), SW71.2
unnamed: D73.2 (A), SW72.2
unnamed: D74.2 (A), SW73.2
unnamed: D75.2 (A), SW74.2
unnamed: D76.2 (A), SW75.2
unnamed: D77.2 (A), SW76.2
unnamed: D78.2 (A), SW77.2
unnamed: D79.2 (A), SW78.2
unnamed: J1.1, U1.25 (BATT+)
unnamed: J1.2, U1.24 (GND)
ROW1: D1.1 (K), D2.1 (K), D3.1 (K), D4.1 (K), D5.1 (K), D6.1 (K), D7.1 (K), D8.1 (K), D9.1 (K), D10.1 (K), D11.1 (K), D12.1 (K), D13.1 (K), D14.1 (K), U4.21 (GPA0)
ROW2: D15.1 (K), D16.1 (K), D17.1 (K), D18.1 (K), D19.1 (K), D20.1 (K), D21.1 (K), D22.1 (K), D23.1 (K), D24.1 (K), D25.1 (K), D26.1 (K), D27.1 (K), D28.1 (K), U4.22 (GPA1)
ROW3: D29.1 (K), D30.1 (K), D31.1 (K), D32.1 (K), D33.1 (K), D34.1 (K), D35.1 (K), D36.1 (K), D37.1 (K), D38.1 (K), D39.1 (K), D40.1 (K), D41.1 (K), D42.1 (K), U4.23 (GPA2)
ROW4: D43.1 (K), D44.1 (K), D45.1 (K), D46.1 (K), D47.1 (K), D48.1 (K), D49.1 (K), D50.1 (K), D51.1 (K), D52.1 (K), D53.1 (K), D54.1 (K), D55.1 (K), U4.24 (GPA3)
ROW5: D56.1 (K), D57.1 (K), D58.1 (K), D59.1 (K), D60.1 (K), D61.1 (K), D62.1 (K), D63.1 (K), D64.1 (K), D65.1 (K), D66.1 (K), D67.1 (K), D68.1 (K), U4.25 (GPA4)
ROW6: D70.1 (K), D71.1 (K), D72.1 (K), D73.1 (K), D74.1 (K), D75.1 (K), D76.1 (K), D77.1 (K), D78.1 (K), D79.1 (K), U4.26 (GPA5)
SCK: U1.9 (IO5), U2.3 (SCL)
SCL: R3.2, R5.2, U1.7 (IO3), U3.12 (SCK), U4.12 (SCK)
SDA: R2.2, R4.2, U1.6 (IO2), U3.13 (SDA), U4.13 (SDA)
SWITCH_BLE: R11.2, SW95.3 (C), U4.28 (GPA7)
SWITCH_USB: R10.2, SW95.1 (A), U4.27 (GPA6)

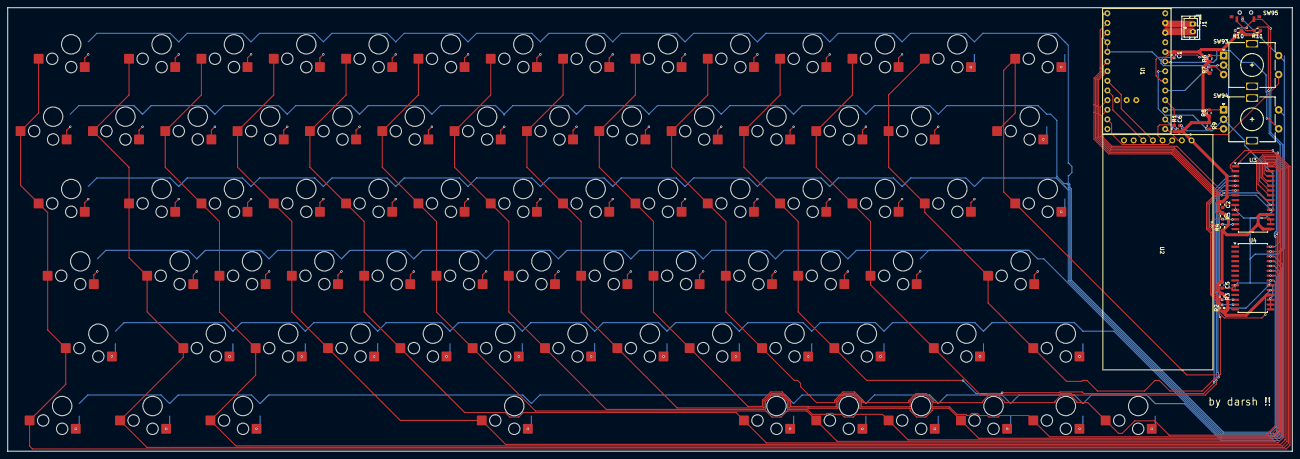
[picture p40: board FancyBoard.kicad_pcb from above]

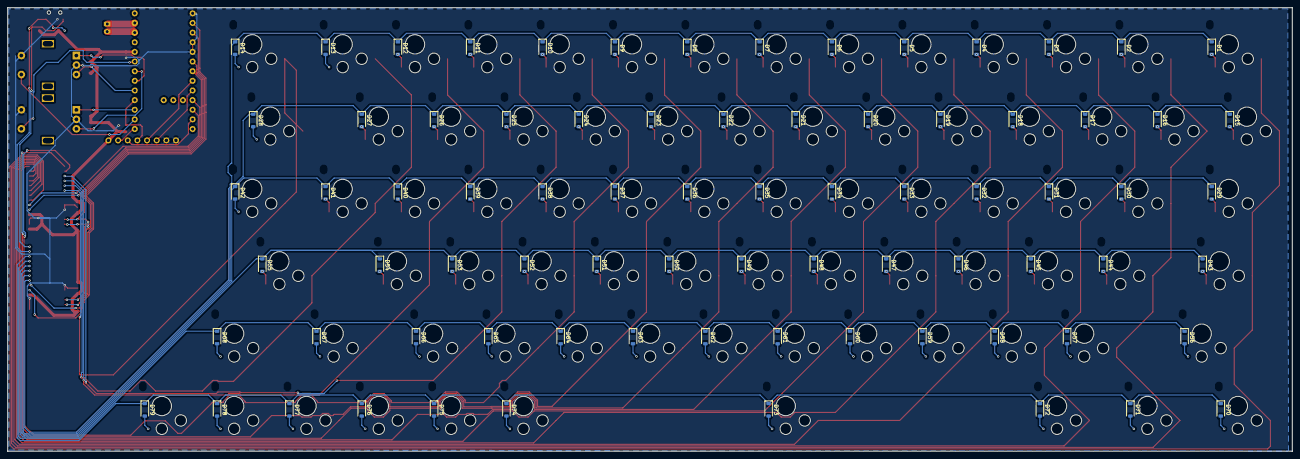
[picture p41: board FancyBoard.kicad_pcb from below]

Board: 2 copper layers, 338.3 x 116.8 mm, 179 parts (78 on the bottom side), 121 nets.

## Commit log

2025-07-29 most of schematic done
    [FancyBoard.kicad_pcb, FancyBoard.kicad_sch]
2025-07-29 schematic done
    [FancyBoard.kicad_sch]
2025-07-30 mostly done pcb
    [FancyBoard.kicad_pcb, FancyBoard.kicad_sch, nice!nano v2.step]
2025-07-30 mostly done routing
    [FancyBoard.kicad_pcb, FancyBoard.kicad_sch, ec11.STEP]
2025-07-30 pcb done?
    [FancyBoard.kicad_pcb, FancyBoard.kicad_sch, Kailh LP Choc Burnt Orange.STEP]
2025-07-31 pcb done
    [Choc_Stem_MX_Size_Normal.step, FancyBoard.kicad_pcb, FancyBoard.kicad_sch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]
2025-07-31 cad mostly done
    [0603 Capacitor.SLDPRT, 0603 Resistor.SLDPRT, 1.00u.SLDPRT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]
2025-08-01 firmware and cad
2025-08-01 finished !!
    [bottom.STEP, draw1.dxf, draw2.dxf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]
2025-08-01 filleted + appearance + render
    [1.25u.SLDPRT, 1.5u.SLDPRT, 1.75.SLDPRT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]
2025-08-02 added more design and new render
    [top.SLDPRT]
2025-08-05 added more to case
    [Kailh LP Choc Burnt Orange.SLDPRT, bottom.SLDPRT, bottom.STEP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]
2025-08-07 added mounting holes
    [FancyBoard BOM.csv, bottom.SLDPRT, bottom.STEP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]
